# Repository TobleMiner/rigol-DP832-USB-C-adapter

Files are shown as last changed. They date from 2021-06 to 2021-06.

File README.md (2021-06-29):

Rigol DP832 USB-C adapter
=========================

This PCB is a dual USB-C port adapter for the Rigol DP832.  
Slotting right onto channel three of the DP832 it provides you with dual
USB-C ports for powering your homemade USB gadgets.

**Note this design is still untested. PCBs are on their way from China but will take
some more weeks**

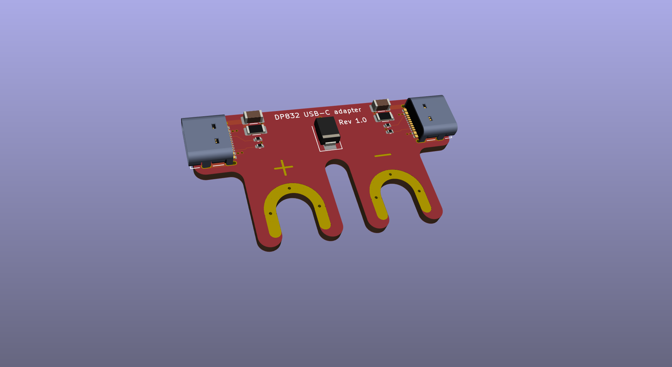
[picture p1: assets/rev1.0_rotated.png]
PCB front


# Limitations

This board is 5V only. No PD negotiation supported.

# Ordering

The fabrication files inside `fab` are JLCPCB-ready. Leave settings at default but select
ENIG surface finish and specify order number location for best results. Also remember to
choose your favourite PCB color ;)  

The zip archive does also contain all files required for JLC assembly. So you can also order
fully assembled boards from JLC.

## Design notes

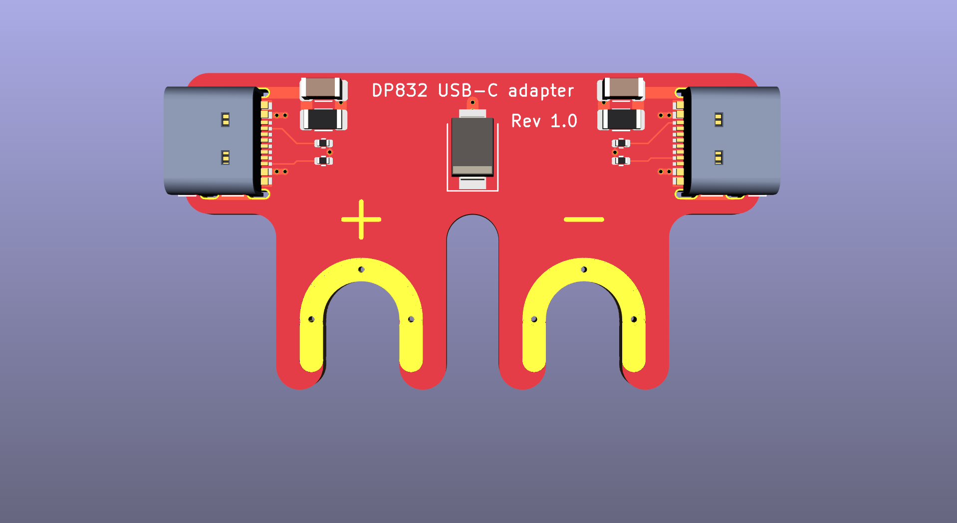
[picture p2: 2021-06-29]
assets/rev1.0_top.png

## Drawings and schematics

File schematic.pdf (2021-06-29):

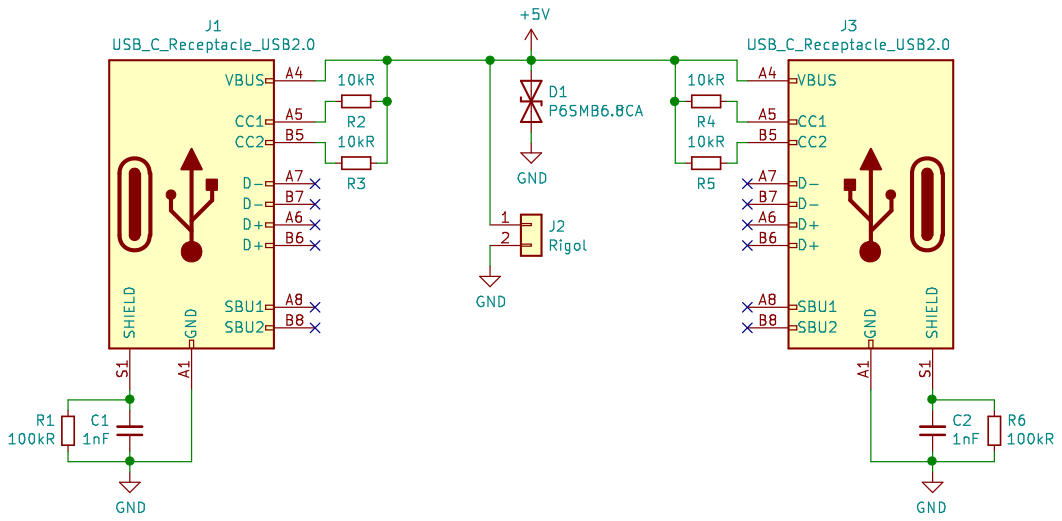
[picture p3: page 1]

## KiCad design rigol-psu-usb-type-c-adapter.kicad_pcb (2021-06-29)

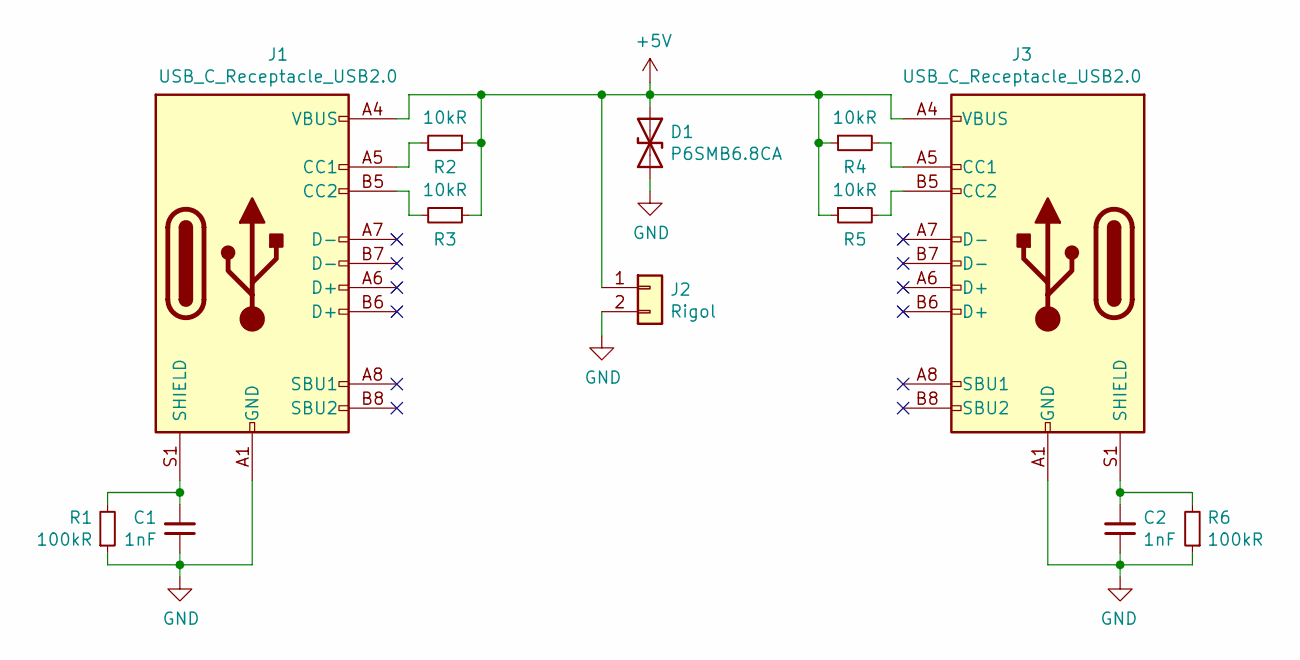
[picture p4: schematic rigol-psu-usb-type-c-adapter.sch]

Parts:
C1, C2: 1nF; C_1206_3216Metric; LCSC C35216
D1: P6SMB6.8CA; D_SMB; LCSC C78395
J1, J3: USB_C_Receptacle_USB2.0; USB_C_Receptacle_Palconn_UTC16-G; LCSC C167321
J2: Rigol; DP832
R1, R6: 100kR; R_1206_3216Metric; LCSC C17900
R2, R3, R4, R5: 10kR; R_0402_1005Metric; LCSC C25725

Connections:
+5V: D1.1 (A1), J1.A4 (VBUS), J1.A9 (VBUS), J1.B4 (VBUS), J1.B9 (VBUS), J2.1, J3.A4 (VBUS), J3.A9 (VBUS), J3.B4 (VBUS), J3.B9 (VBUS), R2.1, R3.1, R4.1, R5.1
GND: C1.1, C2.1, D1.2 (A2), J1.A1 (GND), J1.A12 (GND), J1.B1 (GND), J1.B12 (GND), J2.2, J3.A1 (GND), J3.A12 (GND), J3.B1 (GND), J3.B12 (GND), R1.1, R6.1
unnamed: C1.2, J1.S1 (SHIELD), R1.2
unnamed: C2.2, J3.S1 (SHIELD), R6.2
unnamed: J1.A5 (CC1), R2.2
unnamed: J1.B5 (CC2), R3.2
unnamed: J3.A5 (CC1), R4.2
unnamed: J3.B5 (CC2), R5.2

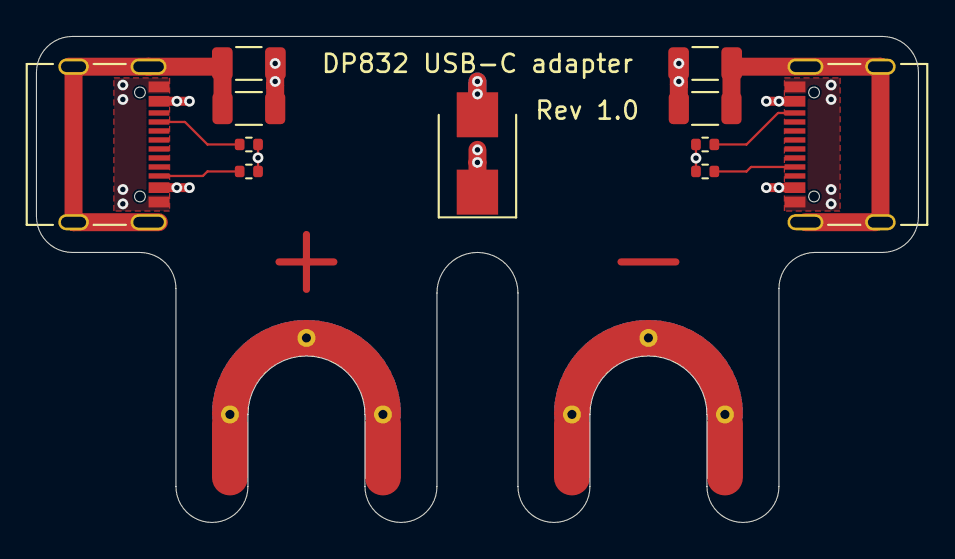
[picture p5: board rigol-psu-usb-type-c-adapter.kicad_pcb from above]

Board: 2 copper layers, 49.0 x 27.0 mm, 12 parts (0 on the bottom side), 8 nets.

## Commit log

2021-06-29 Fix CC pull-ups
    Memory fooled me. They need to be 10kR, not 5.1kR.
    [rigol-psu-usb-type-c-adapter.kicad_pcb, rigol-psu-usb-type-c-adapter.sch]
2021-06-29 Add schematic export
2021-06-29 Add assembly files
2021-06-29 Fix CC resistor part number
    [rigol-psu-usb-type-c-adapter.sch]
